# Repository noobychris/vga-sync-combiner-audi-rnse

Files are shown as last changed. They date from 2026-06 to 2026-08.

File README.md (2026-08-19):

# VGA Sync Combiner for Audi RNS-E, 74HCT86 based

<p align="center">
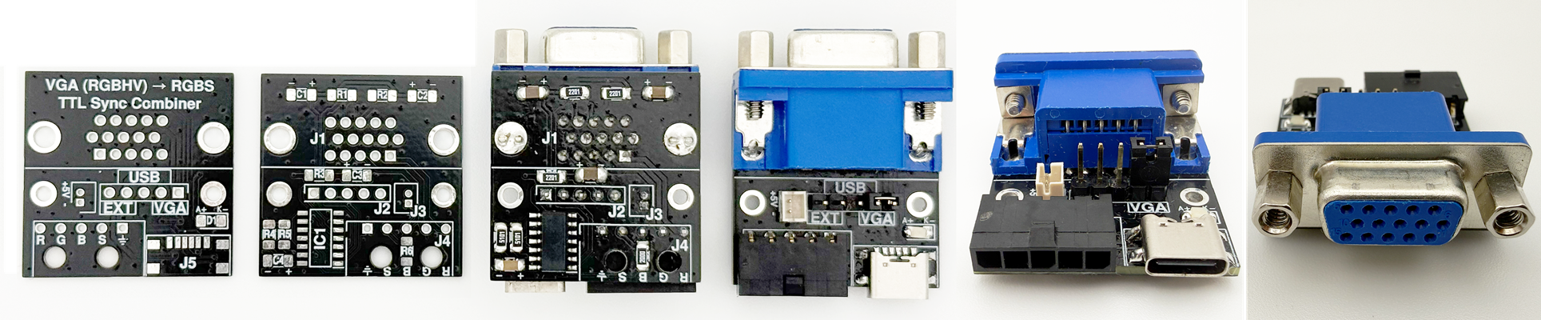
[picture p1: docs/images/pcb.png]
PCB
  
</p>

This project contains a small KiCad PCB for converting a VGA-style RGBHV signal into an RGBS signal suitable for the RGB video input of an Audi RNS-E navigation unit.

The board was designed for use with HDMI-to-VGA adapters or similar VGA/RGBHV sources. It passes the red, green and blue video signals through and combines the separate horizontal and vertical sync signals into one composite sync signal.

The circuit is based on the VGA to RGB+CSYNC adapter by Tomi Engdahl. The PCB is not a direct 1:1 copy of the original TTL output circuit. It adapts the basic 74HCT86 sync-combiner concept for this specific RNS-E use case, including a series resistor on the C-Sync output and practical connector/power options.

## Purpose

The Audi RNS-E RGB input expects RGBS video, while common VGA sources output RGBHV. This board converts the sync part from RGBHV to RGBS by combining H-Sync and V-Sync into one C-Sync signal. The RGB video lines are routed directly through the PCB.

## PCB

The PCB is designed to be hand-solder friendly. It uses larger SMD packages where practical, mainly 1206 passives and an SOIC-14 logic IC. The layout is intended for manual assembly rather than automated production.

The capacitors are MLCC parts, so they are non-polarized and can be soldered in either orientation. This avoids polarity mistakes during manual assembly.

Power for the logic IC can be selected by jumper:

| PCB label | Power source | Description | Notes |
|---|---|---|---|
| `VGA` | VGA +5V | Via VGA Pin 9 | Requires an HDMI-to-VGA converter that supplies +5V on VGA Pin 9. Not all converters do this. Check the tested converter table before using this option. |
| `USB` | USB-C +5V | Via USB-C connector | Use this option if the converter does not provide +5V on VGA Pin 9. |
| `EXT` | External +5V | Via external JST input | Optional external 5V supply. Check the polarity marked on the PCB before applying power. |

> **Important:** Only one jumper position and one 5V power source must be used at a time. Do not connect multiple 5V sources simultaneously.

A converter may work correctly for video output while still not supplying +5V on VGA Pin 9. In that case, power the PCB through `USB` or `EXT`.

**Only one jumper position and one 5V power source must be used at a time. Do not connect multiple 5V sources simultaneously.**

The external JST input is intended as an optional 5V supply. Its polarity is marked directly on the PCB. Check polarity before applying power.

## Specifications

- Input: VGA RGBHV
- Output: RGBS (Composite Sync)
- Supply voltage: 5 V DC
- Typical current consumption: 15–20 mA
- Supported logic ICs:
  - 74HCT86 (recommended)
  - 74LS86 (supported)
- PCB dimensions: 31 × 31 mm
- PCB thickness: 1.6 mm

## ⚠️ Sync combiner operates without external power

In some setups, the sync combiner may appear to work even when no power supply is connected. This can happen due to backfeeding through the HSync and VSync input signals.

This is unintended behavior and should not be used as a valid power source. Always power the sync combiner from one of the supported 5V inputs.

## Tested (Micro) HDMI to VGA Converters with Raspberry Pi 4B &nbsp;&nbsp;&nbsp; 

**Recommended converter:**  

> The **Hama Video Adapter HDMI™ Plug to VGA Socket (00200344)** is the recommended option for this PCB. It has been tested successfully and provides +5 V on VGA pin 9, allowing the sync combiner to be powered directly through the VGA connection.
>
> Since the Hama adapter has a standard HDMI plug, a **Micro-HDMI-to-HDMI adapter, cable or compatible Raspberry Pi HDMI connector adapter** is additionally required.
>
> Since it has a female VGA output, a **VGA male-to-male gender changer** is also required.

| Converter | HDMI Input | VGA Output | HDMI Adapter | VGA Gender Changer | Price | Result | +5V on VGA Pin 9 | Recommendation | Link |
|---|---|---|---|---|---|---|---|---|---|
| 🏆 **Hama Video Adapter HDMI™ Plug to VGA Socket (00200344)** | HDMI | female | ✅ Required | ✅ Required | ~17 € | ✅ Working | ✅ Yes | ⭐ **Recommended** | [Hama](https://nordics.hama.com/00200344/hama-video-adapter-hdmi-plug-vga-socket-full-hd-1080p) |
| Official Raspberry Pi Micro-HDMI to VGA Cable | Micro HDMI | male | ❌ No | ❌ No | ~7 € | ✅ Working | ❌ No | Alternative with external PCB power | [The Pi Hut](https://thepihut.com/products/official-raspberry-pi-micro-hdmi-to-vga-cable) |
| Male Micro HDMI to Female VGA Adapter Active | Micro HDMI | female | ❌ No | ✅ Required | ~4 € | ✅ Working | ❌ No | Alternative with external PCB power | [AliExpress](https://aliexpress.com/item/1005006115048037.html) |
| BENFEI HDMI to VGA Adapter | HDMI | female | ✅ Required | ✅ Required | ~7 € | ✅ Working | ❌ No | Alternative with external PCB power | [Amazon](https://www.amazon.de/dp/B075GZ8DX7) |
| Twozoh Micro HDMI to VGA Adapter | Micro HDMI | male | ❌ No | ❌ No | ~14 € | ⚠️ Occasional picture interruptions | ✅ Yes | Not recommended | [Amazon](https://www.amazon.de/dp/B0CC9CVRDV) |
| Twozoh HDMI to VGA Adapter | HDMI | male | ✅ Required | ❌ No | ~14 € | ⚠️ Occasional picture interruptions | ✅ Yes | Not recommended | [Amazon](https://www.amazon.de/dp/B0BNTPLYZL) |
| Delock Adapter HDMI Micro-D male to VGA female (65470) | Micro HDMI | female | ❌ No | ✅ Required | ~16 € | ❌ Not working at all | ❌ No | Incompatible | [DeLock](https://www.delock.de/produkt/65470/merkmale.html?setLanguage=en) |

**HDMI Adapter:** A Micro-HDMI-to-HDMI adapter or cable is required for converters with a standard HDMI input when used with the Raspberry Pi 4B.

**VGA Gender Changer:** A VGA male-to-male gender changer is required for converters with a female VGA output.
## Optional EDID installer

This repository also includes an optional `install_edid.sh` script for the Audi RNS-E Raspberry Pi display setup.

The script can install/test EDID files or apply custom `800x480` HDMI timings. It is mainly intended for experimenting with the RNS-E RGB/RGBS video input and different HDMI/VGA or scaler setups.

I have included two `800x480` EDID files for the 193 / 2010 RNS-E:

```text
Karmannsport_RNSE_EDID.bin
pcbbc_Rpi_RNSE_800x480i_EDID.bin
```

## Audi RNS-E Connection

The board was made for an Audi RNS-E RGBS input setup. The RGB and C-Sync output can be wired to the corresponding RNS-E AV/RGB connector pins.
See the [Audi RNS-E pinout](docs/images/rns-e_pinout.jpg) for the connector reference.

## Case

A matching 3D-printable case is included. The case is intended to protect the PCB and make the adapter easier to install in a vehicle or cable harness.

<p align="center">
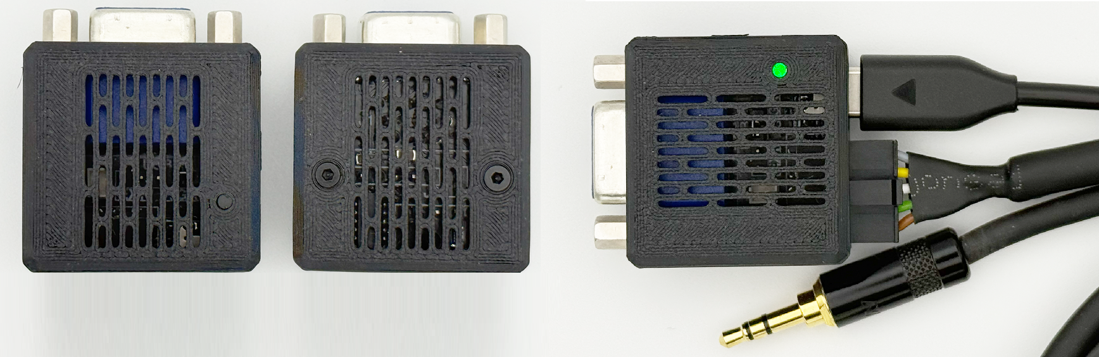
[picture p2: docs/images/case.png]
3D printable case
  
</p>

The case files are located in:

```text
3d_print_case/
├─ vga_sync_combiner.3mf
├─ vga_sync_combiner.stl
└─ 3d_models/
   ├─ vga_sync_combiner_case.step
   └─ vga_sync_combiner_with_all_pcb_parts.step
```

## Repository structure

```text
/
├─ 3d_print_case/
│  ├─ 3d_models/
│  ├─ vga_sync_combiner.3mf
│  └─ vga_sync_combiner.stl
├─ bom/
│  ├─ bom_vga_sync_combiner_for_audi_rns-e_complete.csv
│  └─ bom_vga_sync_combiner_for_audi_rns-e_assembly_service.csv
├─ docs/
│  └─ images/
├─ edid_installer/
│  ├─ edid/
│  │  ├─ Karmannsport_RNSE_EDID.bin
│  │  └─ pcbbc_Rpi_RNSE_800x480i_EDID.bin
│  └─ install_edid.sh
├─ kicad_files/
│  ├─ 3dmodels/
│  ├─ gerber_to_order/
│  │  ├─ vga_sync_combiner_for_audi_rns-e_31.0x31.0mm_for_Default.zip
│  │  ├─ vga_sync_combiner_for_audi_rns-e_31.0x31.0mm_for_Elecrow.zip
│  │  ├─ vga_sync_combiner_for_audi_rns-e_31.0x31.0mm_for_FusionPCB.zip
│  │  ├─ vga_sync_combiner_for_audi_rns-e_31.0x31.0mm_for_JLCPCB.zip
│  │  └─ vga_sync_combiner_for_audi_rns-e_31.0x31.0mm_for_PCBWay.zip
│  ├─ vga_sync_combiner_for_rns-e_footprints.pretty/
│  ├─ vga_sync_combiner_for_rns-e_symbols.kicad_sym
│  ├─ vga_sync_combiner_for_audi_rns-e.kicad_pro
│  ├─ vga_sync_combiner_for_audi_rns-e.kicad_sch
│  ├─ vga_sync_combiner_for_audi_rns-e.kicad_pcb
│  └─ vga_sync_combiner_for_audi_rns-e.kicad_prl
└─ README.md
````

The BOM is located at:

```text
kicad_files/vga_sync_combiner_for_audi_rns-e.csv
```

The BOM also includes parts that are not mounted directly on the PCB, such as cables, crimp contacts, connector housings and jumper/shunt parts. It is therefore intended as a complete project BOM, not necessarily as a direct assembly BOM for PCB assembly services.

## Notes

This board is intended for experimental/custom RNS-E video input builds. It is not an official Audi product and has no relation to Audi.

The original Engdahl circuit is a TTL-level sync combiner. This PCB keeps the 74HCT86-based sync-combiner principle, but the output stage is adapted for this project. Depending on the target device, video source and wiring, the C-Sync output resistor may need adjustment.

## Credits

The sync-combining logic is based on the original [VGA to RGB + composite sync converter](https://www.epanorama.net/circuits/vga2rgbs.html) circuit by Tomi Engdahl, 1993–1996.

The included PCB adapts the concept for an Audi RNS-E RGBS input use case.

<p align="center">
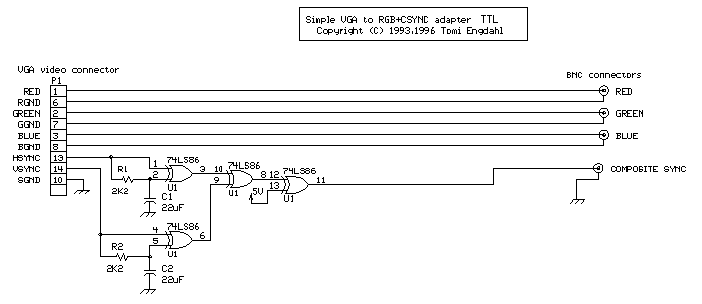
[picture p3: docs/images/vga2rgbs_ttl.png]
Original Engdahl VGA to RGBS schematic
  
</p>

## License

The hardware design files in this repository, including schematics,
PCB layouts, Gerber files, manufacturing files, and documentation,
are licensed under the CERN Open Hardware Licence Version 2 –
Permissive (CERN-OHL-P-2.0).

See the [LICENSE](LICENSE) file for the full license text.

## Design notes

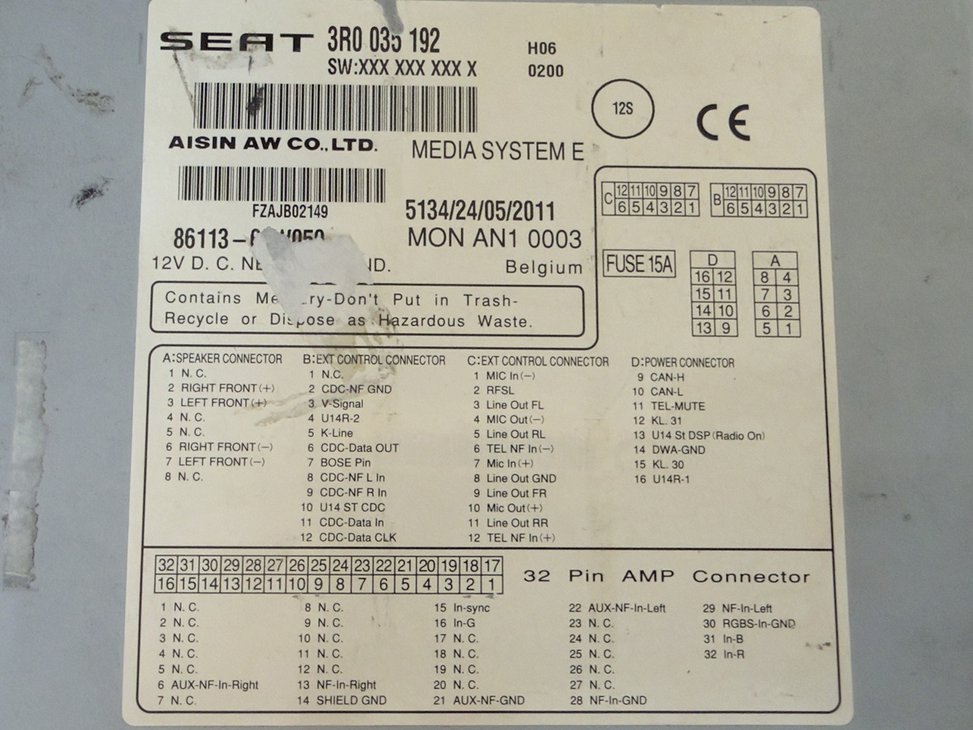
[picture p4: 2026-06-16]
docs/images/rns-e_pinout.jpg

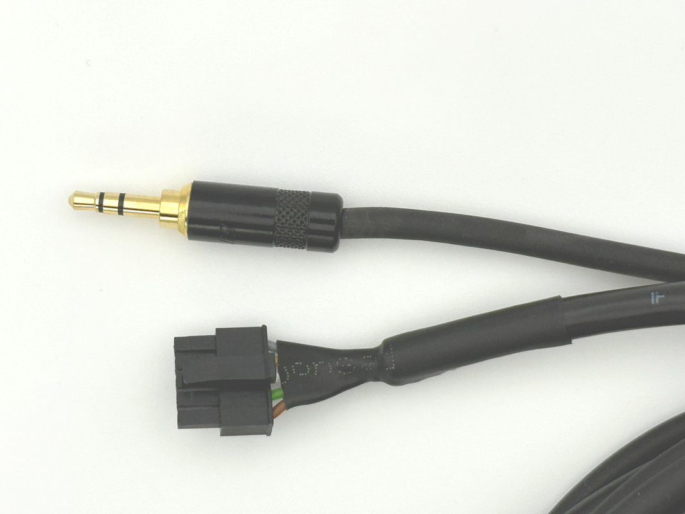
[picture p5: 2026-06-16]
docs/images/cable.png

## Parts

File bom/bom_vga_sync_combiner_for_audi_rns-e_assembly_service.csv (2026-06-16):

# | Reference | Category | Qty | Price | Value | Manufacturer_Name | Manufacturer_Part_Number | Mouser Part Number | Alternative Mouser Part Number | Length | Purchase-URL | DNP | Exclude from BOM | Exclude from Board | Package | Description | Footprint | Datasheet | Availability
1 | C1,C2 | PCB | 2 | 0,58 € | 22uF | KEMET | C1206C226M4PACTU | 80-C1206C226M4P |  |  | https://mou.sr/4tZFwct |  |  |  | 1206 | 22µF 16V X5R MLCC, 1206, non-polarized. Sync delay capacitor for HSync/VSync XOR sync combiner. | vga_sync_combiner_footprints:C_1206_3216Metric_Pad1.33x1.80mm_HandSolder | https://www.mouser.de/datasheet/3/72/1/C1206C226M4PACTU.pdf | In Stock
2 | C3 | PCB | 1 | 0,58 € | 22uF | KEMET | C1206C226M4PACTU | 80-C1206C226M4P |  |  | https://mou.sr/4tZFwct |  |  |  | 1206 | 22µF 16V X5R MLCC, 1206, non-polarized. +5V_LOAD bulk / input buffer capacitor after power-source jumper. | vga_sync_combiner_footprints:C_1206_3216Metric_Pad1.33x1.80mm_HandSolder | https://www.mouser.de/datasheet/3/72/1/C1206C226M4PACTU.pdf | In Stock
3 | C4 | PCB | 1 | 0,45 € | 100nF | KEMET | C1206C104J4RACTU | 80-C1206C104J4R |  |  | https://mou.sr/42HmjR3 |  |  |  | 1206 | 100nF 16V X7R MLCC, 1206, non-polarized. Local decoupling capacitor for IC1 VCC/GND. | vga_sync_combiner_footprints:C_1206_3216Metric_Pad1.33x1.80mm_HandSolder | https://www.mouser.de/datasheet/3/508/1/KEM_C1002_X7R_SMD.pdf | In Stock
4 | D1 | PCB | 1 | 1,03 € | PWR_LED | Broadcom / Avago | HSMQ-C150 | 630-HSMQ-C150 |  |  | https://mou.sr/46z2M7Y |  |  |  | 1206 | Broadcom 527 nm Green LED, 3216 (1206) SMD package | vga_sync_combiner_footprints:LEDC3216X120N | https://docs.broadcom.com/docs/AV02-0977EN | In Stock
5 | IC1 | PCB | 1 | 0,34 € | 74HCT86 | Texas Instruments | CD74HCT86M96 | 595-CD74HCT86M96 |  |  | https://mou.sr/4gXf9yn |  |  |  | SOIC-14 | High Speed CMOS Logic Quad 2-Input Exclusive-OR Gates | vga_sync_combiner_footprints:SOIC127P600X175-14N | http://www.ti.com/lit/gpn/cd74hct86 | In Stock
6 | J1 | PCB | 1 | 1,50 € | VGA_RGBHV_IN | Amphenol | L77HDE15SD1CH4F | 523-L77HDE15SD1CH4F | 523-7HDE15SD1CH4FVGA |  | https://mou.sr/4mSe1Ny |  |  |  | HD-15 Right Angle THT | Amphenol ICC HD-15 VGA Socket, Right Angle PCB Through Hole, 15 Position, 4-40 Front Screwlock, Ground Tab, Boardlock. Alternative: L77HDE15SD1CH4FVGA, blue VGA version with matching footprint/pinout. | vga_sync_combiner_footprints:L77HDE15SD1CH4F | https://cdn.amphenol-cs.com/media/wysiwyg/files/drawing/l77hdxxxsd1ch4f.pdf | In Stock
7 | J2 | PCB | 1 | 0,22 € | POWER_SOURCE_JUMPER_HEADER | Wurth Elektronik | 61300511121 | 710-61300511121 |  |  | https://mou.sr/4720HR3 |  |  |  | Pin Header 1x5 2.54mm | 2.54MM PIN HEADER, 5 position | vga_sync_combiner_footprints:HDRV5W64P0X254_1X5_1270X254X854P | http://katalog.we-online.de/em/datasheet/6130xx11121.pdf | In Stock
8 | J3 | PCB | 1 | 0,09 € | JST ZR 1x2 Header | JST | B2B-ZR(LF)(SN) | 306-B2BZRLFSNP |  |  | https://mou.sr/3W1Ls5A |  |  |  | JST ZR 1x2 1.5mm THT | JST ZR Series 1.5mm Pitch, 2 Way, 1 Row, Shrouded Top Entry PCB Header, Through Hole | vga_sync_combiner_footprints:SHDR2W50P0X150_1X2_450X350X450P | https://componentsearchengine.com/Datasheets/2/B2B-ZR(LF)(SN).pdf | In Stock
9 | J4 | PCB | 1 | 2,14 € | RGBS_OUT_PCB_HEADER | TE Connectivity | 2-1445098-5 | 571-2-1445098-5 |  |  | https://mou.sr/42nyMJL |  |  |  | Micro-MATE-N-LOK 5P RA THT Header | TE Connectivity Micro-MATE-N-LOK 5 Position Right Angle PCB Mount Header, 3mm Pitch, Wire-to-Board, for RGBS_OUT | vga_sync_combiner_footprints:214450985 | https://www.te.com/commerce/DocumentDelivery/DDEController?Action=srchrtrv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 | In Stock
10 | J5 | PCB | 1 | 0,55 € | USB-C | GCT (GLOBAL CONNECTOR TECHNOLOGY) | USB4135-GF-A | 640-USB4135-GF-A |  |  | https://mou.sr/3J7hTfS |  |  |  | USB-C RA SMD Power-Only | GCT USB Type-C Receptacle, Power-Only, Right Angle SMD, USB4135-GF-A | vga_sync_combiner_footprints:USB4135GFA | https://www.mouser.com/catalog/specsheets/GCT_USb4135_Product_Drawing.pdf | In Stock
11 | R1,R2 | PCB | 2 | 0,17 € | 2k2 | Panasonic | ERJ-P08F2201V | 667-ERJ-P08F2201V |  |  | https://mou.sr/3QTzMT6 |  |  |  | 1206 | 2.2kΩ 1% resistor, 1206. RC delay resistor for HSync/VSync XOR sync combiner. | vga_sync_combiner_footprints:R_1206_3216Metric_Pad1.30x1.75mm_HandSolder | https://industrial.panasonic.com/cdbs/www-data/pdf/RDO0000/AOA0000C331.pdf | In Stock
12 | R3 | PCB | 1 | 0,17 € | 2k2 | Panasonic | ERJ-P08F2201V | 667-ERJ-P08F2201V |  |  | https://mou.sr/3QTzMT6 |  |  |  | 1206 | 2.2kΩ 1% resistor, 1206. Power LED series resistor. | vga_sync_combiner_footprints:R_1206_3216Metric_Pad1.30x1.75mm_HandSolder | https://industrial.panasonic.com/cdbs/www-data/pdf/RDO0000/AOA0000C331.pdf | In Stock
13 | R4,R5 | PCB | 2 | 0,17 € | 5k1 | Panasonic | ERJ-P08F5101V | 667-ERJ-P08F5101V |  |  | https://mou.sr/4n2RMou |  |  |  | 1206 | 5.1kΩ 1% resistor, 1206. USB-C CC pull-down resistor for 5V sink detection. | vga_sync_combiner_footprints:R_1206_3216Metric_Pad1.30x1.75mm_HandSolder | https://industrial.panasonic.com/cdbs/www-data/pdf/RDO0000/AOA0000C331.pdf | In Stock
14 | R6 | PCB | 1 | 0,17 € | 200R | Panasonic | ERJ-P08F2000V | 667-ERJ-P08F2000V |  |  | https://mou.sr/4cXvcM7 |  |  |  | 1206 | 200Ω 1% resistor, 1206. C-Sync output series resistor. | vga_sync_combiner_footprints:R_1206_3216Metric_Pad1.30x1.75mm_HandSolder | https://industrial.panasonic.com/cdbs/www-data/pdf/RDO0000/AOA0000C331.pdf | In Stock

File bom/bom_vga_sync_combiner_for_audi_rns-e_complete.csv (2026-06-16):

# | Reference | Category | Qty | Price | Value | Manufacturer_Name | Manufacturer_Part_Number | Mouser Part Number | Alternative Mouser Part Number | Length | Purchase-URL | DNP | Exclude from BOM | Exclude from Board | Package | Description | Footprint | Datasheet | Availability
1 | C1,C2 | PCB | 2 | 0,58 € | 22uF | KEMET | C1206C226M4PACTU | 80-C1206C226M4P |  |  | https://mou.sr/4tZFwct |  |  |  | 1206 | 22µF 16V X5R MLCC, 1206, non-polarized. Sync delay capacitor for HSync/VSync XOR sync combiner. | vga_sync_combiner_footprints:C_1206_3216Metric_Pad1.33x1.80mm_HandSolder | https://www.mouser.de/datasheet/3/72/1/C1206C226M4PACTU.pdf | In Stock
2 | C3 | PCB | 1 | 0,58 € | 22uF | KEMET | C1206C226M4PACTU | 80-C1206C226M4P |  |  | https://mou.sr/4tZFwct |  |  |  | 1206 | 22µF 16V X5R MLCC, 1206, non-polarized. +5V_LOAD bulk / input buffer capacitor after power-source jumper. | vga_sync_combiner_footprints:C_1206_3216Metric_Pad1.33x1.80mm_HandSolder | https://www.mouser.de/datasheet/3/72/1/C1206C226M4PACTU.pdf | In Stock
3 | C4 | PCB | 1 | 0,45 € | 100nF | KEMET | C1206C104J4RACTU | 80-C1206C104J4R |  |  | https://mou.sr/42HmjR3 |  |  |  | 1206 | 100nF 16V X7R MLCC, 1206, non-polarized. Local decoupling capacitor for IC1 VCC/GND. | vga_sync_combiner_footprints:C_1206_3216Metric_Pad1.33x1.80mm_HandSolder | https://www.mouser.de/datasheet/3/508/1/KEM_C1002_X7R_SMD.pdf | In Stock
4 | CBL1 | Cable | 1 | ~3,20 € | LAPP UNITRONIC LiYCY 5x0.34 BK | LAPP | 1030498 |  |  | ~1.5-2.0m |  |  |  | Excluded from board | Cable, 5x0.34mm² + Shield | Shielded RGBS cable, LAPP UNITRONIC LiYCY 5x0.34mm², black. Carries R, G, B, C-Sync and GND to the Audi RNS-E connector. |  | https://contentmedia.lappcdn.com/e/lapp/uatTXagpWEsffD0incR4mw~~/DB1030450DE.pdf
5 | CBL2 | Cable | 1 | ~2,60€ | Cordial CPK 220 BK | Cordial | 10969 |  |  | ~1.5-2.0m |  |  |  | Excluded from board | Cable, 2x0.20mm² + Shield | Shielded stereo audio cable, Cordial CPK 220 BK. Carries left/right audio and ground to the 3.5mm TRS plug. |  | https://www.cordial-cables.com/product-pictures/bulk-cable/cpk220/cpk-220.pdf
6 | CP1,CP2,CP3,CP4,CP5 | Cable | 5 | 0,09 € | RGBS_OUT_PIN | TE Connectivity | 794610-1 | 571-794610-1 | 571-1-794610-1 |  | https://mou.sr/46T0jUX |  |  | Excluded from board | Micro-MATE-N-LOK Socket Contact | TE Micro-MATE-N-LOK crimp socket contacts, 20–24 AWG, for RGBS_OUT cable housing J7. Excluded from board, included in BOM. |  | https://www.te.com/commerce/DocumentDelivery/DDEController?Action=srchrtrv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 | In Stock
7 | CP7,CP8,CP9,CP10,CP11,CP12 | Cable | 6 | 0,09 € | RNS-E_MQS_PIN | TE Connectivity | 5-928999-1 | 571-5-928999-1 |  |  | https://mou.sr/3XqVYVs |  |  | Excluded from board | TE MQS 0.63 mm Receptacle, Crimp | TE MQS 0.63mm female crimp contacts, 0.20–0.35mm² / 22–24 AWG, for Audi/RNS-E 32-pin connector J9. Excluded from board, included in BOM. |  | https://www.te.com/commerce/DocumentDelivery/DDEController?Action=srchrtrv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 | In Stock
8 | D1 | PCB | 1 | 1,03 € | PWR_LED | Broadcom / Avago | HSMQ-C150 | 630-HSMQ-C150 |  |  | https://mou.sr/46z2M7Y |  |  |  | 1206 | Broadcom 527 nm Green LED, 3216 (1206) SMD package | vga_sync_combiner_footprints:LEDC3216X120N | https://docs.broadcom.com/docs/AV02-0977EN | In Stock
9 | IC1 | PCB | 1 | 0,34 € | 74HCT86 | Texas Instruments | CD74HCT86M96 | 595-CD74HCT86M96 |  |  | https://mou.sr/4gXf9yn |  |  |  | SOIC-14 | High Speed CMOS Logic Quad 2-Input Exclusive-OR Gates | vga_sync_combiner_footprints:SOIC127P600X175-14N | http://www.ti.com/lit/gpn/cd74hct86 | In Stock
10 | J1 | PCB | 1 | 1,50 € | VGA_RGBHV_IN | Amphenol | L77HDE15SD1CH4F | 523-L77HDE15SD1CH4F | 523-7HDE15SD1CH4FVGA |  | https://mou.sr/4mSe1Ny |  |  |  | HD-15 Right Angle THT | Amphenol ICC HD-15 VGA Socket, Right Angle PCB Through Hole, 15 Position, 4-40 Front Screwlock, Ground Tab, Boardlock. Alternative: L77HDE15SD1CH4FVGA, blue VGA version with matching footprint/pinout. | vga_sync_combiner_footprints:L77HDE15SD1CH4F | https://cdn.amphenol-cs.com/media/wysiwyg/files/drawing/l77hdxxxsd1ch4f.pdf | In Stock
11 | J2 | PCB | 1 | 0,22 € | POWER_SOURCE_JUMPER_HEADER | Wurth Elektronik | 61300511121 | 710-61300511121 |  |  | https://mou.sr/4720HR3 |  |  |  | Pin Header 1x5 2.54mm | 2.54MM PIN HEADER, 5 position | vga_sync_combiner_footprints:HDRV5W64P0X254_1X5_1270X254X854P | http://katalog.we-online.de/em/datasheet/6130xx11121.pdf | In Stock
12 | J3 | PCB | 1 | 0,09 € | JST ZR 1x2 Header | JST | B2B-ZR(LF)(SN) | 306-B2BZRLFSNP |  |  | https://mou.sr/3W1Ls5A |  |  |  | JST ZR 1x2 1.5mm THT | JST ZR Series 1.5mm Pitch, 2 Way, 1 Row, Shrouded Top Entry PCB Header, Through Hole | vga_sync_combiner_footprints:SHDR2W50P0X150_1X2_450X350X450P | https://componentsearchengine.com/Datasheets/2/B2B-ZR(LF)(SN).pdf | In Stock
13 | J4 | PCB | 1 | 2,14 € | RGBS_OUT_PCB_HEADER | TE Connectivity | 2-1445098-5 | 571-2-1445098-5 |  |  | https://mou.sr/42nyMJL |  |  |  | Micro-MATE-N-LOK 5P RA THT Header | TE Connectivity Micro-MATE-N-LOK 5 Position Right Angle PCB Mount Header, 3mm Pitch, Wire-to-Board, for RGBS_OUT | vga_sync_combiner_footprints:214450985 | https://www.te.com/commerce/DocumentDelivery/DDEController?Action=srchrtrv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 | In Stock
14 | J5 | PCB | 1 | 0,55 € | USB-C | GCT (GLOBAL CONNECTOR TECHNOLOGY) | USB4135-GF-A | 640-USB4135-GF-A |  |  | https://mou.sr/3J7hTfS |  |  |  | USB-C RA SMD Power-Only | GCT USB Type-C Receptacle, Power-Only, Right Angle SMD, USB4135-GF-A | vga_sync_combiner_footprints:USB4135GFA | https://www.mouser.com/catalog/specsheets/GCT_USb4135_Product_Drawing.pdf | In Stock
15 | J6 | Cable | 1 | 1,11 € | JST ZR 1x2 Cable | JST | A02ZR02ZR28H254A | 306-A02ZR02ZR28H254A |  |  | https://mou.sr/4q7f7be |  |  | Excluded from board | JST ZR 1x2 Cable | JST ZR 2-pin cable assembly for optional external 5V input. Excluded from board, included in complete BOM. PCB polarity: Pin 2 = +5V, Pin 1 = GND. |  | https://www.mouser.de/datasheet/3/1070/1/GAM-299.pdf | In Stock
16 | J7 | Cable | 1 | 0,27 € | RGBS_OUT_HOUSING (Cable) | TE Connectivity | 1445022-5 | 571-14450225 |  |  | https://mou.sr/42nZGRI |  |  | Excluded from board | Micro-MATE-N-LOK 5P Receptacle Housing | TE Micro-MATE-N-LOK 5-position cable housing for RGBS output cable. Excluded from board, included in complete BOM. |  | https://www.te.com/commerce/DocumentDelivery/DDEController?Action=srchrtrv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 | In Stock
17 | J8 | Cable | 1 | 1,98 € | REAN NYS231BG | REAN | NYS231BG | 568-NYS231BG |  |  | https://mou.sr/4g7GmQd |  |  | Excluded from board | 3.5mm TRS Plug | Audio Jack, 3 Poles (Stereo / TRS)
18 | J9 | Cable | 1 | 2,00 € | AUDI_RNS-E_32_Pin_AMP_Connector | Audi | 1J0972977 |  |  |  | https://kufatec.com/de/audi-rns-e-video-stecker-32-polig/37900 |  |  | Excluded from board | Audi RNS-E 32-pin connector housing | Audi/VW 32-pin RNS-E AV connector housing for RGBS/audio cable connection. Excluded from board, included in complete BOM.
19 | JMP1 | Accessory | 1 | 0,27 € | POWER_SOURCE_JUMPER | Wurth Elektronik | 60900213421 | 710-60900213421 |  |  | https://mou.sr/3QI8haK |  |  | Excluded from board | 2.54mm Jumper/Shunt | Jumper, 2-pole, closed/bridged |  | https://www.we-online.com/components/products/datasheet/60900213421.pdf | In Stock
20 | R1,R2 | PCB | 2 | 0,17 € | 2k2 | Panasonic | ERJ-P08F2201V | 667-ERJ-P08F2201V |  |  | https://mou.sr/3QTzMT6 |  |  |  | 1206 | 2.2kΩ 1% resistor, 1206. RC delay resistor for HSync/VSync XOR sync combiner. | vga_sync_combiner_footprints:R_1206_3216Metric_Pad1.30x1.75mm_HandSolder | https://industrial.panasonic.com/cdbs/www-data/pdf/RDO0000/AOA0000C331.pdf | In Stock
21 | R3 | PCB | 1 | 0,17 € | 2k2 | Panasonic | ERJ-P08F2201V | 667-ERJ-P08F2201V |  |  | https://mou.sr/3QTzMT6 |  |  |  | 1206 | 2.2kΩ 1% resistor, 1206. Power LED series resistor. | vga_sync_combiner_footprints:R_1206_3216Metric_Pad1.30x1.75mm_HandSolder | https://industrial.panasonic.com/cdbs/www-data/pdf/RDO0000/AOA0000C331.pdf | In Stock
22 | R4,R5 | PCB | 2 | 0,17 € | 5k1 | Panasonic | ERJ-P08F5101V | 667-ERJ-P08F5101V |  |  | https://mou.sr/4n2RMou |  |  |  | 1206 | 5.1kΩ 1% resistor, 1206. USB-C CC pull-down resistor for 5V sink detection. | vga_sync_combiner_footprints:R_1206_3216Metric_Pad1.30x1.75mm_HandSolder | https://industrial.panasonic.com/cdbs/www-data/pdf/RDO0000/AOA0000C331.pdf | In Stock
23 | R6 | PCB | 1 | 0,17 € | 200R | Panasonic | ERJ-P08F2000V | 667-ERJ-P08F2000V |  |  | https://mou.sr/4cXvcM7 |  |  |  | 1206 | 200Ω 1% resistor, 1206. C-Sync output series resistor. | vga_sync_combiner_footprints:R_1206_3216Metric_Pad1.30x1.75mm_HandSolder | https://industrial.panasonic.com/cdbs/www-data/pdf/RDO0000/AOA0000C331.pdf | In Stock

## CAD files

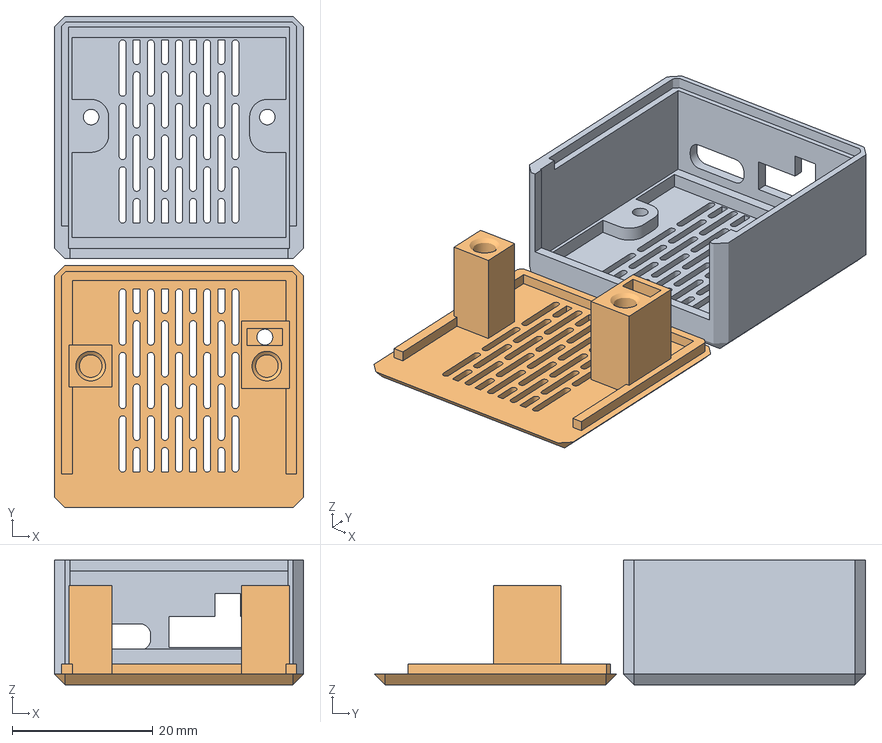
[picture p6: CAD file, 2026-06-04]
3d_print_case/vga_sync_combiner_for_rns-e_case.3mf
35.4 x 69.7 x 17.7 mm
Seiten_usb-c
Deckel 2.25mm Plexi Rundstab

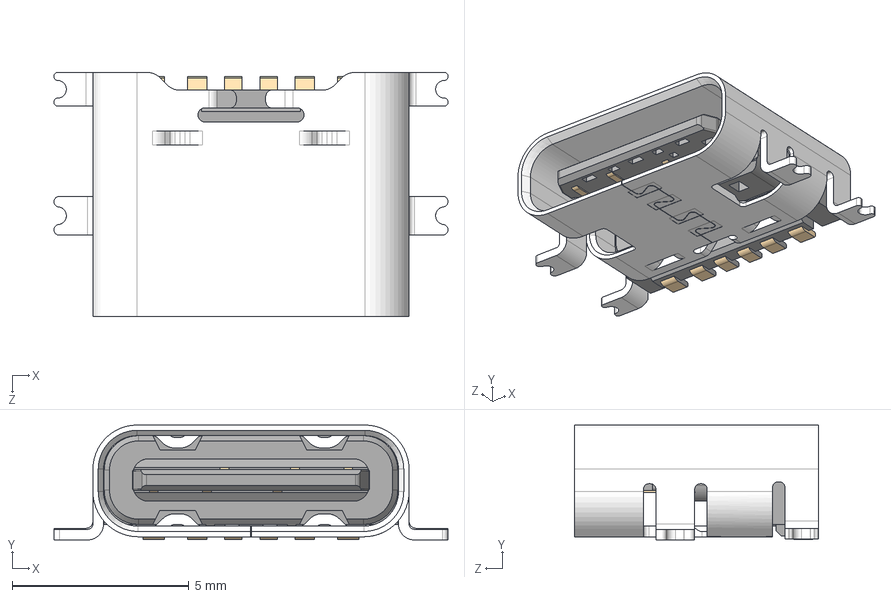
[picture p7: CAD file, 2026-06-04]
kicad_files/3dmodels/USB4135-GF-A.stp
11.1 x 3.25 x 6.90 mm
USB4135-GF-A
USB4135-GF-A_2

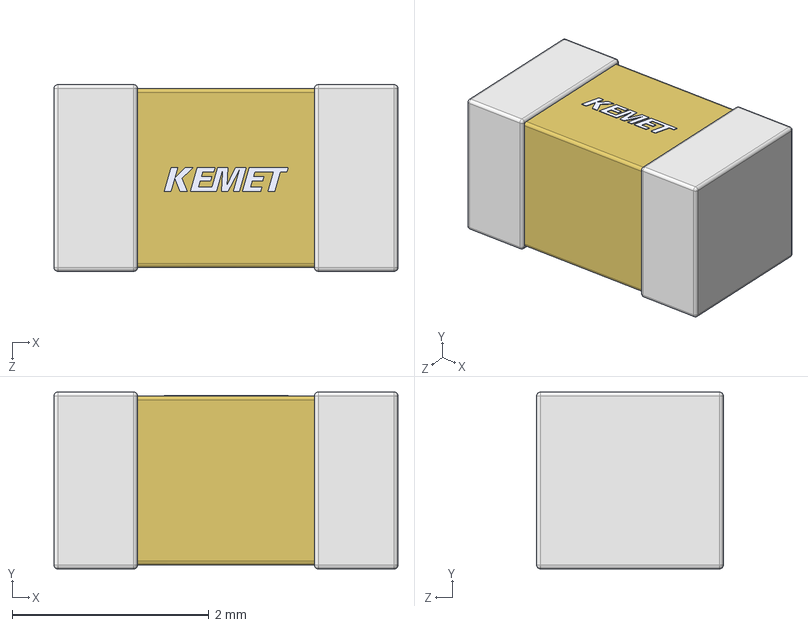
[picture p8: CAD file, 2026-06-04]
kicad_files/3dmodels/C1206C226M4PACTU.stp
3.50 x 1.80 x 1.90 mm

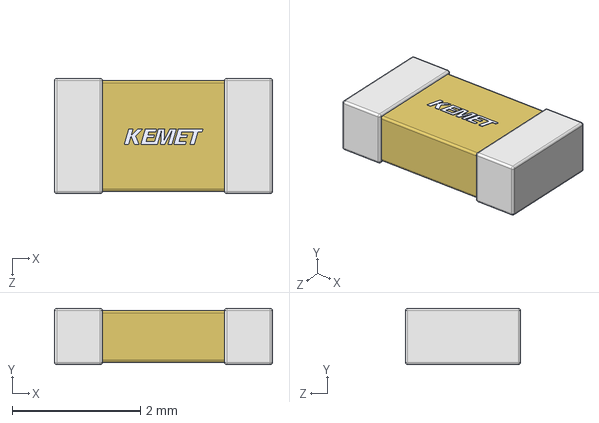
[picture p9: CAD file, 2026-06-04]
kicad_files/3dmodels/C1206C104J4RACTU.stp
3.40 x 0.88 x 1.80 mm

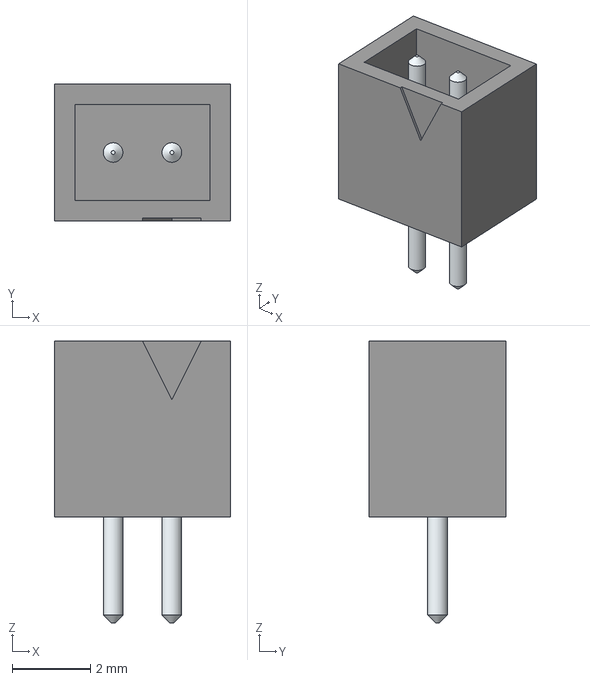
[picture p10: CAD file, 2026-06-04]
kicad_files/3dmodels/B2B-ZR_LF__SN_.stp
4.50 x 3.50 x 7.20 mm
LeadsArray

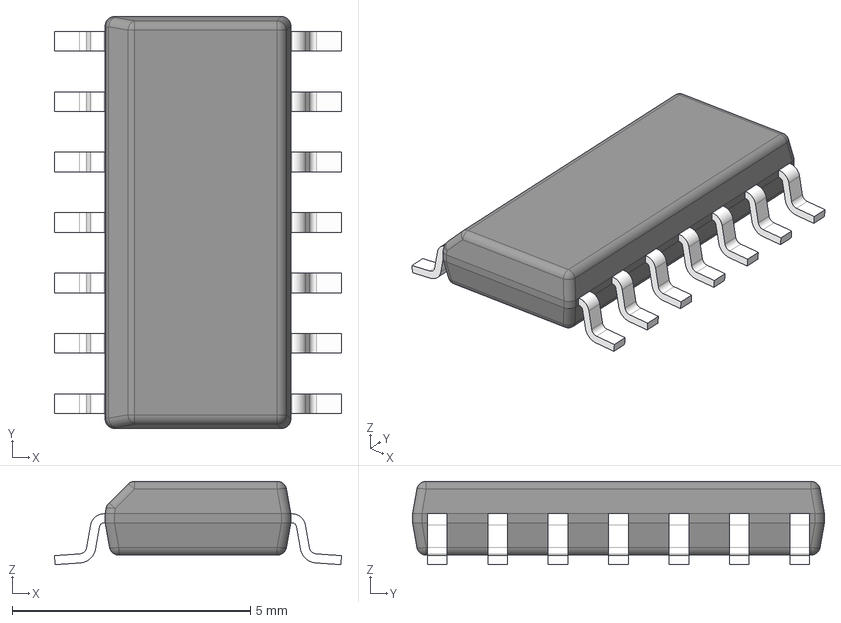
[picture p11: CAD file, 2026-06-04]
kicad_files/3dmodels/CD74HCT86M96.stp
6.03 x 8.65 x 1.75 mm
BODY-SO
LEAD-SO x 14
PIN1-ID

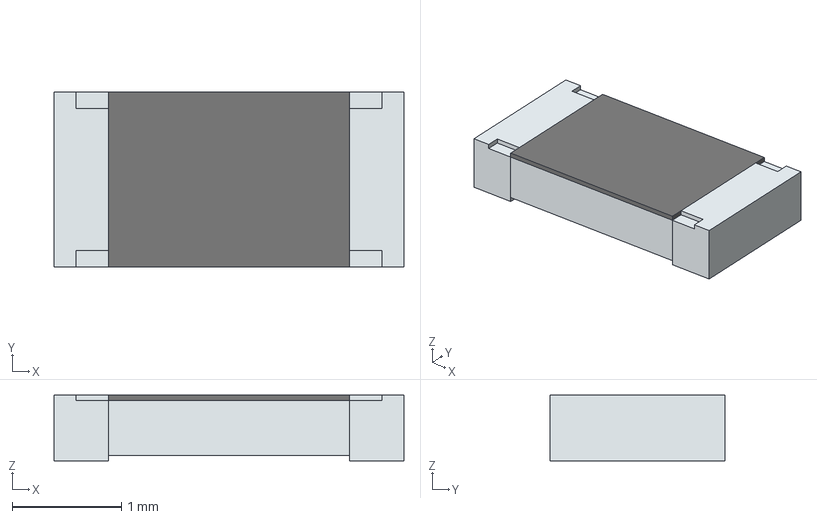
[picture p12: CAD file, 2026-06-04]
kicad_files/3dmodels/ERJ-U08F2201V.stp
3.20 x 1.60 x 0.6 mm
solidBody
Terminal
solidTop

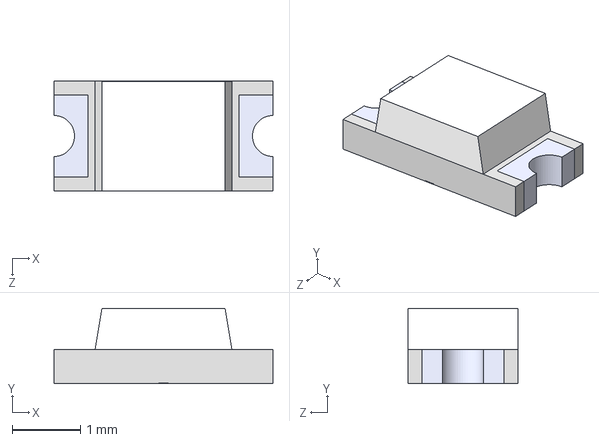
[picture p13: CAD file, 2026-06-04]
kicad_files/3dmodels/HSMQ-C150.stp
3.20 x 1.10 x 1.60 mm

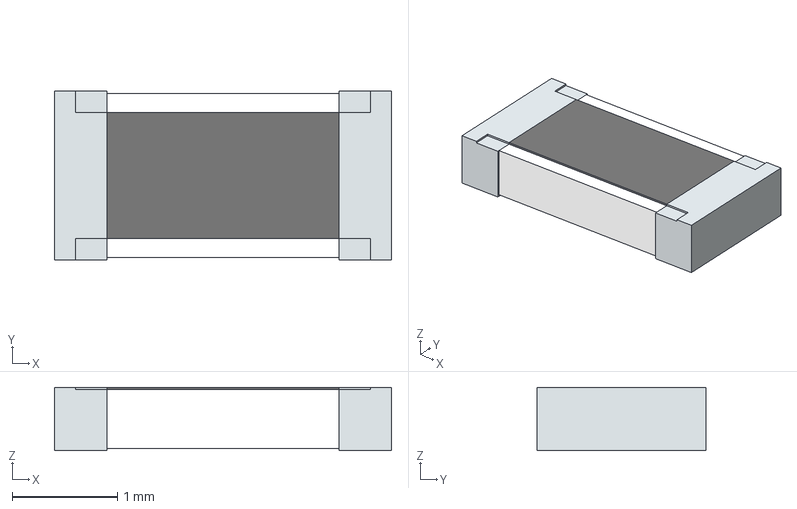
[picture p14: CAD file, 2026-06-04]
kicad_files/3dmodels/ERA-8AEB681V.stp
3.20 x 1.60 x 0.6 mm
solidBody
Terminal
solidTop

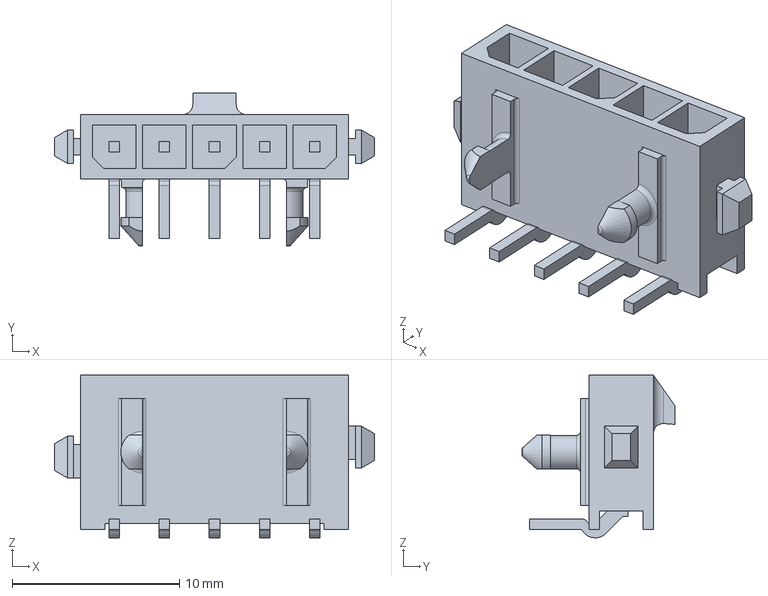
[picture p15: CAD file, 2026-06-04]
kicad_files/3dmodels/2-1445098-5.stp
19.1 x 9.18 x 9.73 mm

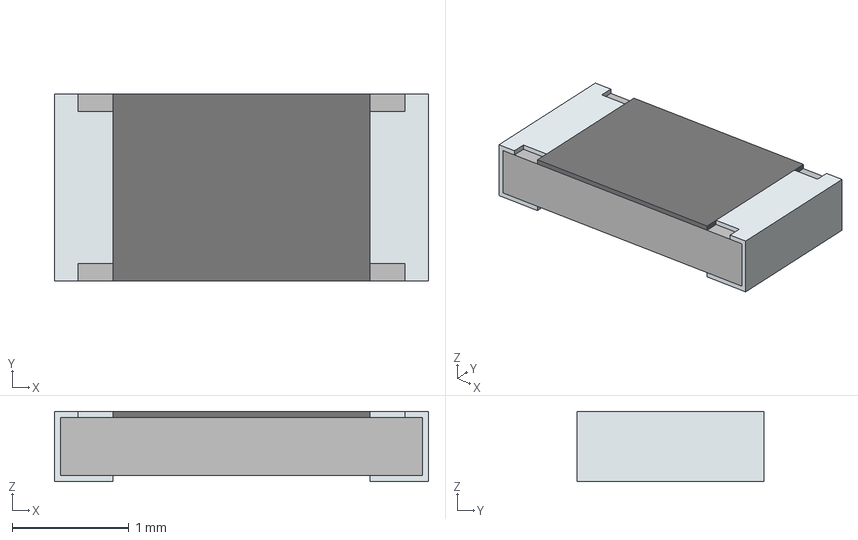
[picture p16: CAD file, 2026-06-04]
kicad_files/3dmodels/ERJ-P08F5101V.stp
3.20 x 1.60 x 0.6 mm
solidBody
Terminal
solidTop

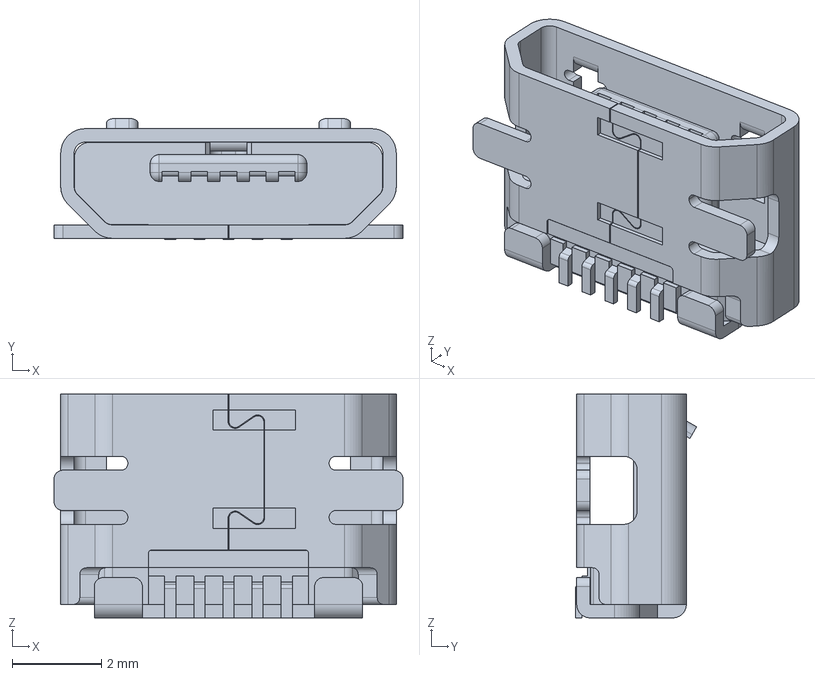
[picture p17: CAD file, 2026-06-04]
kicad_files/3dmodels/47346-1001.stp
7.80 x 2.71 x 5.00 mm

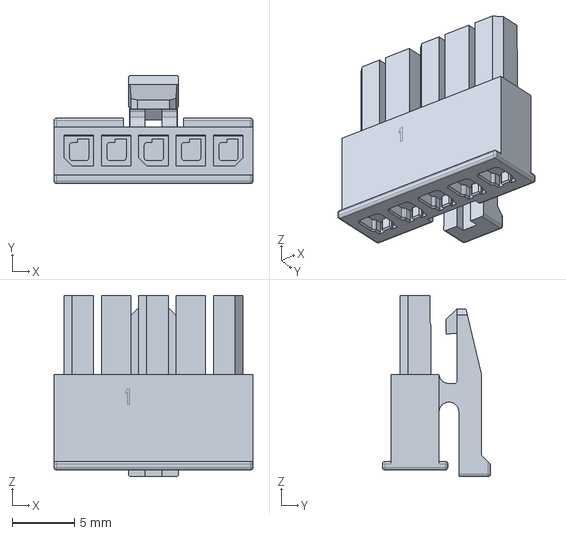
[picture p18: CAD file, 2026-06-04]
kicad_files/3dmodels/1445022-5.stp
16.0 x 8.70 x 14.6 mm

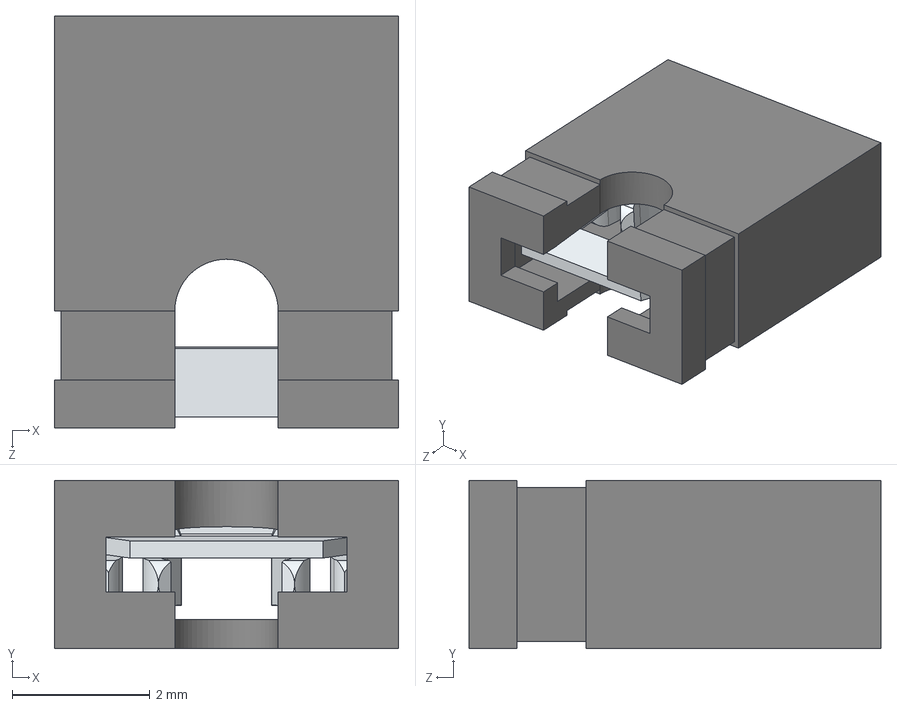
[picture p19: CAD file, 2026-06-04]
kicad_files/3dmodels/60900213421.stp
5.00 x 2.44 x 5.98 mm
60900213421_Housing

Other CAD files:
3d_print_case/3d_models/vga_sync_combiner_for_rns-e_pcb_and_case.step
kicad_files/3dmodels/61300511121.stp
3d_print_case/vga_sync_combiner_for_rns-e_case.stl

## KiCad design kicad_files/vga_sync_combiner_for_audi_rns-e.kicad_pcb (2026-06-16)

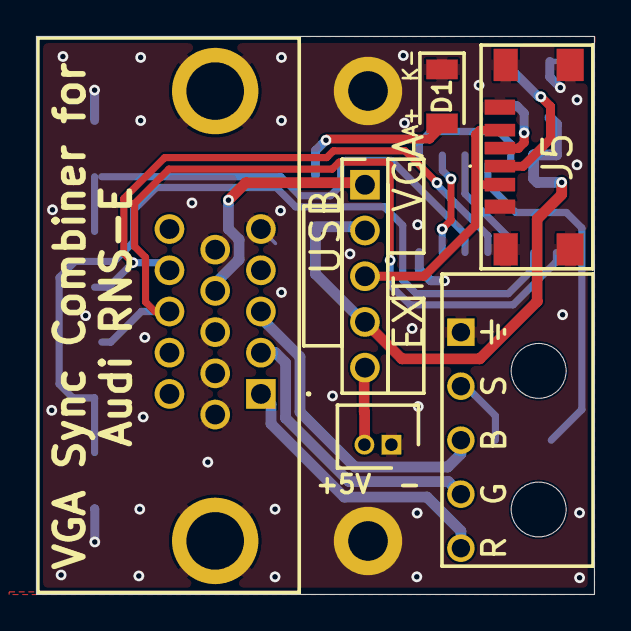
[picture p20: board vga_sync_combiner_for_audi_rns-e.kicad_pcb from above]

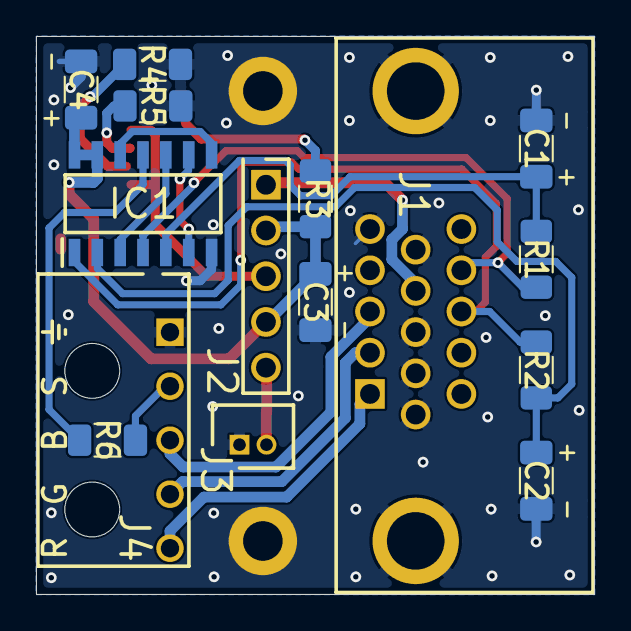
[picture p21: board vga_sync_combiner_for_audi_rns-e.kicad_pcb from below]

Board: 2 copper layers, 31.0 x 31.0 mm, 19 parts (11 on the bottom side), 20 nets.

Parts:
C1, C2, C3: 22uF; C_1206_3216Metric_Pad1.33x1.80mm_HandSolder
C4: 100nF; C_1206_3216Metric_Pad1.33x1.80mm_HandSolder
D1: PWR_LED; LEDC3216X120N
H1, H2: MountingHole_Pad; MountingHole_2.2mm_M2_DIN965_Pad
IC1: 74HCT86; SOIC127P600X175-14N
J1: VGA_RGBHV_IN; L77HDE15SD1CH4F
J2: POWER_SOURCE_JUMPER_HEADER; HDRV5W64P0X254_1X5_1270X254X854P
J3: JST ZR 1x2 Header; SHDR2W50P0X150_1X2_450X350X450P
J4: RGBS_OUT_PCB_HEADER; 214450985
J5: USB-C; USB4135GFA
R1, R2, R3: 2k2; R_1206_3216Metric_Pad1.30x1.75mm_HandSolder
R4, R5: 5k1; R_1206_3216Metric_Pad1.30x1.75mm_HandSolder
R6: 200R; R_1206_3216Metric_Pad1.30x1.75mm_HandSolder

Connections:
/+5V_JST: J2.5, J3.2
/+5V_LOAD: C3.1 (+), C4.1, IC1.13 (4B), IC1.14 (VCC), J2.2, J2.4, R3.1
/+5V_USB: J2.3, J5.A9, J5.B9
/+5V_VGA: J1.9, J2.1
/BLUE: J1.3, J4.3
/CC1: J5.A5, R4.1
/CC2: J5.B5, R5.1
/C_SYNC_OUT: J4.2, R6.2
/C_SYNC_PRE_R: IC1.11 (4Y), R6.1
/C_SYNC_RAW: IC1.8 (3Y), IC1.12 (4A)
/GREEN: J1.2, J4.4
/H_SYNC_DLY: C2.1 (+), IC1.2 (1B), R2.2
/H_SYNC_IN: IC1.1 (1A), J1.13, R2.1
/H_XOR_OUT: IC1.3 (1Y), IC1.10 (3B)
/LED_PWR: D1.2 (A), R3.2
/RED: J1.1, J4.5
/V_SYNC_DLY: C1.1 (+), IC1.5 (2B), R1.2
/V_SYNC_IN: IC1.4 (2A), J1.14, R1.1
/V_XOR_OUT: IC1.6 (2Y), IC1.9 (3A)
GND: C1.2 (-), C2.2 (-), C3.2 (-), C4.2, D1.1 (K), H1.1 (1_1), H2.1 (1_1), IC1.7 (GND), J1.5, J1.6, J1.7, J1.8, J1.10, J1.16 (MH1), J1.17 (MH2), J3.1, J4.1, J5.A12, J5.B12, J5.MP1, J5.MP2, J5.MP3, J5.MP4, R4.2, R5.2

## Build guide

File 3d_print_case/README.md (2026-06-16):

# 3D Printed Case

<p align="center">
  3D printable case
</p>

This folder contains a 3D-printable case for the VGA RGBHV to RGBS / C-Sync Combiner PCB.

The case is designed to hold the PCB and protect it during installation or use in a cable harness. It uses two M2 heat-set inserts and two M2 countersunk screws to close the case.

## Print Material

PETG, ABS or ASA are recommended for the case. PLA may work for testing, but is not recommended for use in a car or other warm environments.

For vehicle use, ABS or ASA is preferred because of the higher temperature resistance. PETG is a reasonable alternative if the case is not exposed to high temperatures.

## Files

```text
3d_print_case/
├─ vga_sync_combiner_for_rns-e_case.3mf
├─ vga_sync_combiner_for_rns-e_case.stl
└─ 3d_models/
   ├─ vga_sync_combiner_for_rns-e.step
   ├─ vga_sync_combiner_for_rns-e_pcb.step
   └─ vga_sync_combiner_for_rns-e_with_all_pcb_parts.step
```

## Required Hardware

| Quantity | Part | Notes |
| :--- | :--- | :--- |
| 2 | M2 heat-set inserts | Maximum length: 7 mm |
| 2 | M2 countersunk screws | Length: 8–12 mm |

## Optional Light Pipe

An optional light pipe can be added for the onboard LED.

| Quantity | Part | Notes |
| :--- | :--- | :--- |
| 1 | Plexiglass / acrylic round rod | 2 mm diameter, approx. 12 mm length |

The hole in the case is designed with a diameter of 2.25 mm. This is intentional, because the used acrylic rod was not perfectly consistent in diameter and was slightly larger than 2.00 mm in some areas.

If your rod fits too loosely or too tightly, adjust the hole or rod diameter accordingly.

## Assembly Notes

After soldering the VGA connector, the ground/shield feet of the VGA connector may need to be shortened slightly. Otherwise they may interfere with the case fit.

<p align="center">
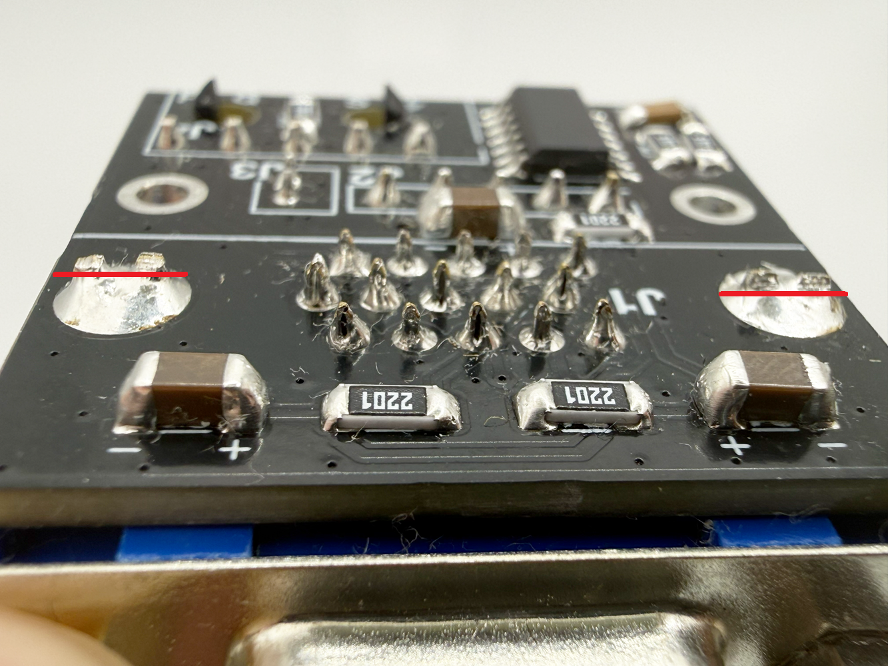
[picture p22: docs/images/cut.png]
PCB
  
</p>

Before closing the case, check that:

- the PCB sits flat in the case
- the VGA connector does not touch the case unexpectedly
